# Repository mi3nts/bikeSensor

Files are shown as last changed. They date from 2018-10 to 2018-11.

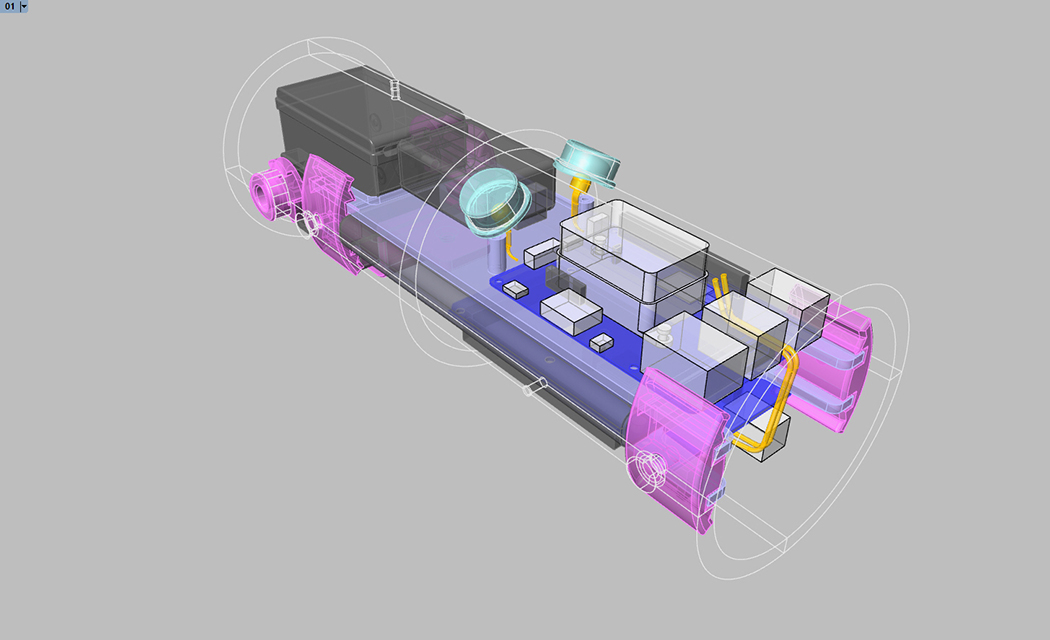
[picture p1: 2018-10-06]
resources/_bikeWaggle_03_FINAL.jpg

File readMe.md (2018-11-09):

# Bike Bottle Design Overview
## Introduction 
Portable devices which can detect airbourne particulates are finding its way into current consumer markets. Unlike there bulky, stationary counterparts the small scale nature of such sensors feeds into a more user friendly, hazzle free platform. The current document proposes such a portable device designed to be fit within a bike bottle housing. Particulate matter is linked with a number of negative health outcomes. Such links are to be addressed with the use of the propesed device.

### Design Specifications  

#### Absolute Necessities 
1. Main Housing:
 - The enclosed device should fit a bike bottle housing.

2. OPC Sensor: 
 - Must have the Alhpa Sense OPC-N3 <br/>
   **http://www.alphasense.com/WEB1213/wp-content/uploads/2018/02/OPC-N3.pdf** <br/>      

3. Automated Notifications 
 - Should sound an alarm when passing through dirty air. 

4. Secondary Sensors: 
- Must have Temprature, Humidity, Pressure and GPS sensors.   

5. Battery:
- Must contain a rechargable portable battery which will enable the device to stay on for atleast for 4 hours.
- Must have an indicator which shows the status of the battery Charge.
- Should be able to work 24*7 when connected to power(Charging pod).

6. Date Storage: 
- The device should be capable of storing at least 24 hours of Data.  
- The Storage output should be a csv 
- Should be accessible to the end user 

7. Weight 
- Must weigh less than 1 Kg.

8. Cost 
- The Whole sensor should cost less than 2000$.

##### Attractive Addons 

1. Secondary Sensors: 
- Inclusion of gas sensors such as NO2 (Nitrogen Dioxide), O3 (Ozone), CO (Carbon Monoxide), SO2 (Sulfer Dioxide), and H2S (Hydrogen Sulfide). 

2. Battery:
- A portable battery which will enable the device to stay on for atleast **24 hours** per charge.

3. Date Storage: 
- Automated Cloud link

4. Mobile App
- Inclusion of an andorid/ios app which will give out live statistics from the data collected.

5. Weight 
- Weigh less than 500g.

6. Cost 
- Getting the cost to be less than 1000$.

7. Wireless Connectivity 
- Inlcussion of a wireless modem and have the possibiilty of WiFi.

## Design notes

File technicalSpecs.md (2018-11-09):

# Bike Sensor
This document specifies the technical specifications for the Bike Waggle Sensor.

## 1.0 Sensor Brain : [Particle Photon](https://docs.particle.io/datasheets/photon-(wifi)/photon-datasheet/)
The main platform used: [Particle IO](https://www.particle.io/). For the sensor brain two options were considered.
- Particle [Photon](https://docs.particle.io/datasheets/photon-(wifi)/photon-datasheet/) : Works with Wi - Fi
- Particle [Electron](https://docs.particle.io/datasheets/electron-(cellular)/electron-datasheet/) : Works on Cellular Data 

It was finalized that **Particle Photon** was to be used due to cost constraints. 

### 1.1 Devices Connecting to the Sensor Brain(Particle Photon)
The sensor hub will be responsible in reading the follwing inputs.

| Part Name | Measurment | Interface  |
|---|---|---|
| GPS Module [NEO-6M](https://www.amazon.com/DIYmall-AeroQuad-Antenna-Arduino-Aircraft/dp/B01H5FNA4K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) | Long/Lat Speed and Altitude  |  RS232 TTL |
| SD Breakout Board [Adafruit-MicroSD](https://www.adafruit.com/product/254) | Read/Write SD | SPI mode |
| RTC Battery [PCF8523](https://www.adafruit.com/product/3295) | Real Time Clock | I2C |
| Gyroscope [MPU9250](https://www.amazon.com/HiLetgo%C2%AE-Gyroscope-Acceleration-Accelerator-Magnetometer/dp/B01I1J0Z7Y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) | 3 axis acceleration - 3 axis orientation - 3 axis magnetometor| I2C|
| Temprature and Humidity Sensor [HTU2ID](https://www.adafruit.com/product/1899) | Temperature - Relative Humidity | I2C |
|Atmospheric Pressure Sensor [BMP280](https://www.amazon.com/Adafruit-BMP280-Barometric-Pressure-Altitude/dp/B01DXCNV2A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) | Temperature -  Atmospheric Pressure | I2C |
|  Alphasense Device [OPC-N3](http://www.alphasense.com/WEB1213/wp-content/uploads/2018/02/OPC-N3.pdf)  | 24 Bin Counts of 0.38 to 40um Spherical Diemetor - PM1 - PM2.5 - PM10| SPI Mode|
| LCD Display [Smraza 2004](https://www.amazon.com/Smraza-Display-characters-Arduino-MEGA2560/dp/B01K1N4XM6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) | Display Output | I2C |

## 2.0 Power Needs

A few more devices are required for a mobile working device. 

- Battery Packs:
    - [Battery Pack 1](https://www.amazon.com/BESWILL-10000MAH-Waterproof-Flashlights-Carabiner/dp/B07BSYZXRT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)
    - [Battery Pack 2](https://www.amazon.com/Portable-RAVPower-26800mAh-Protective-Hermitshell/dp/B01KX3854Q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)
    - [Battery Pack 3](https://www.amazon.com/Soluser-13500mAh-Portable-External-Flashlight/dp/B0728NQ1VK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)
- [Power Tester](https://www.amazon.com/DROK-Multimeter-Voltmeter-Capacitance-Charging/dp/B00J3JSEG6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)

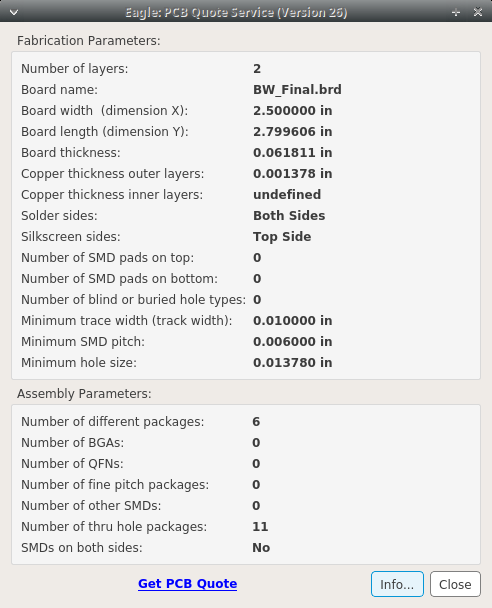
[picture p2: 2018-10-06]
pcbDesign/pcbDetails.png

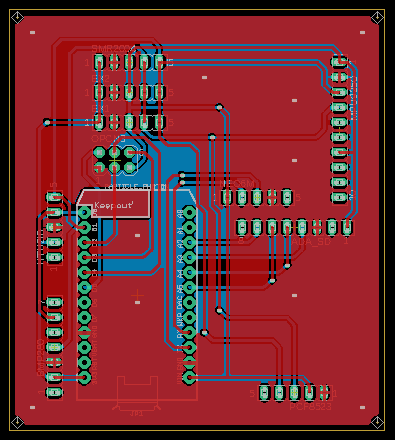
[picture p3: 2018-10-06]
pcbDesign/pcb.png

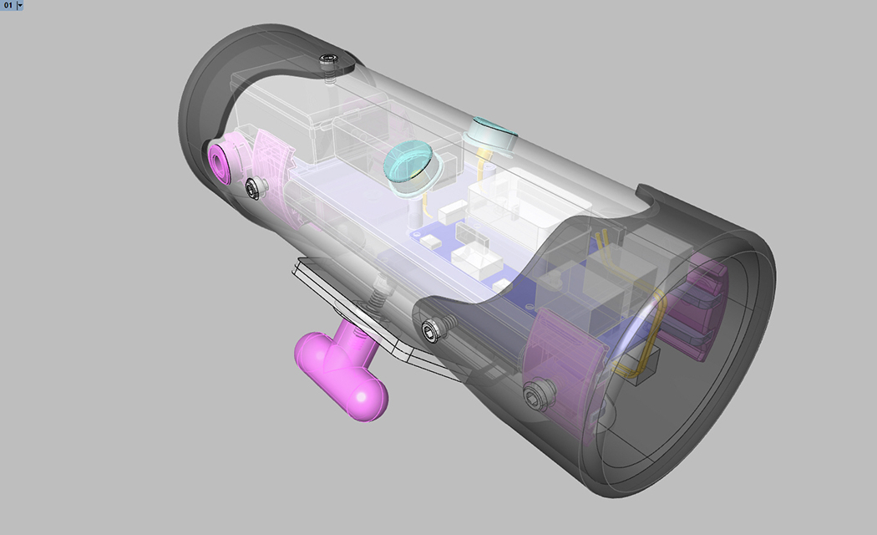
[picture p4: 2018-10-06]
resources/_bikeWaggle_02_FINAL.jpg

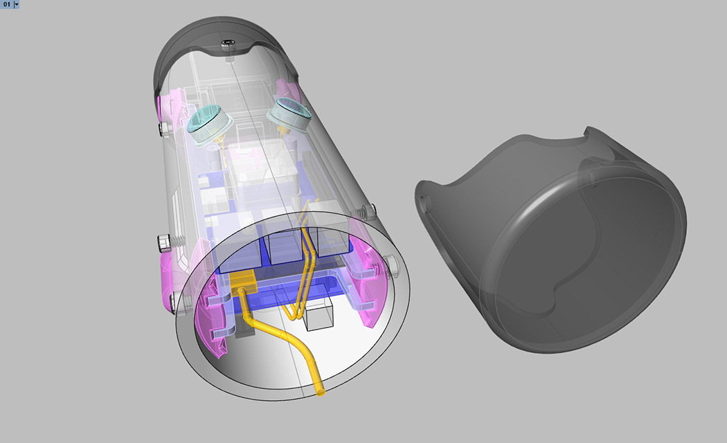
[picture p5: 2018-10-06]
resources/_bikeWaggle_07_FINAL.jpg

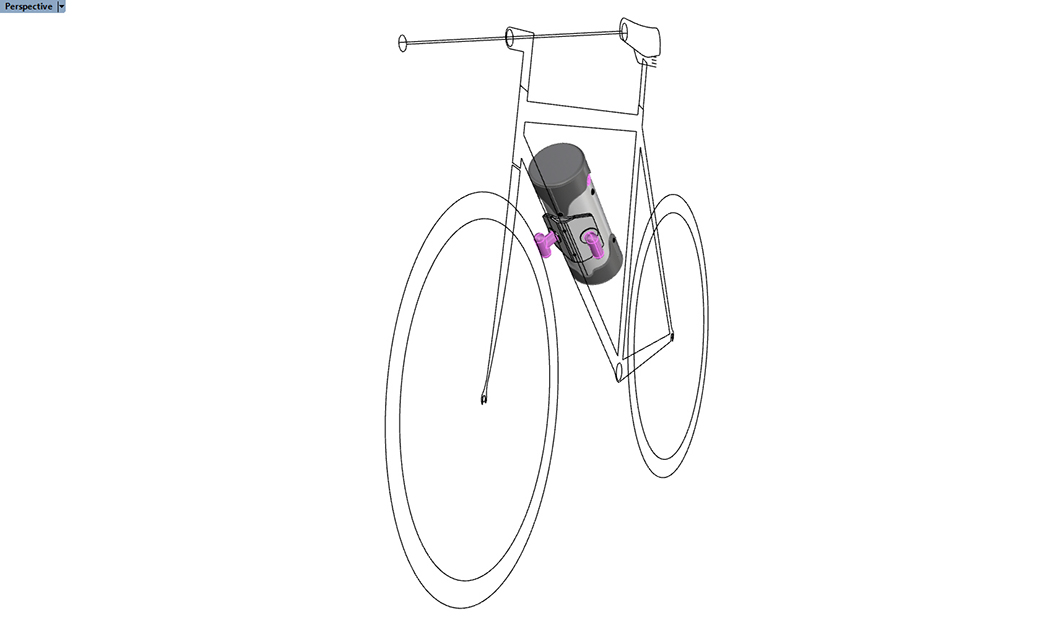
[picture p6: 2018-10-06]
resources/_bikeWaggle_10_FINAL.jpg

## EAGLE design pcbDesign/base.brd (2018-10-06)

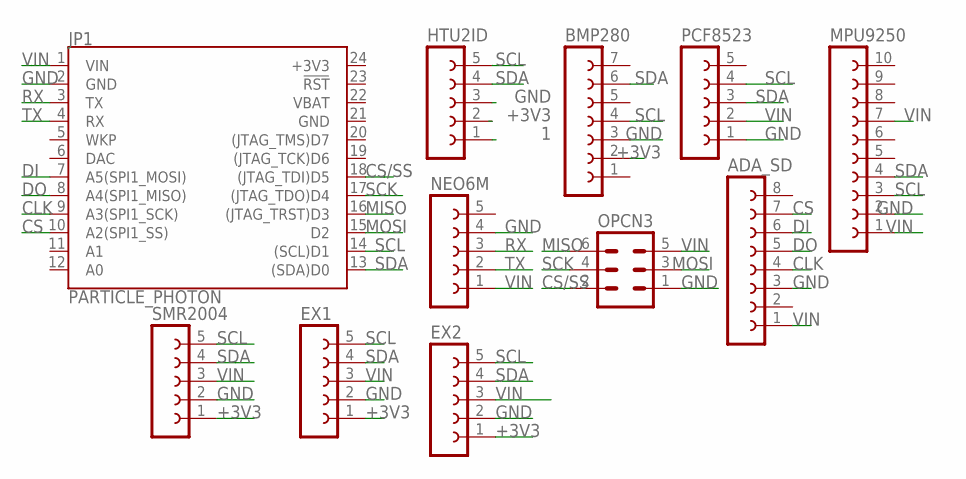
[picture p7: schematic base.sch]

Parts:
ADA_SD: FE08-1; FE08
BMP280: FE07-1; FE07
EX1, EX2: FE05-1
HTU2ID: FE05-1
JP1: PARTICLE_PHOTON
MPU9250: FE10-1; FE10
NEO6M: FE05-1
OPCN3: MA03-2
PCF8523: FE05-1
SMR2004: FE05-1

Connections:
1: HTU2ID.1
+3V3: BMP280.2, EX1.1, EX2.1, HTU2ID.2, JP1.24 (+3V3), SMR2004.1
CLK: ADA_SD.4, JP1.9 (A3(SPI1_SCK))
CS: ADA_SD.7, JP1.10 (A2(SPI1_SS))
CS/SS: JP1.18 ((JTAG_TDI)D5), OPCN3.2
DI: ADA_SD.6, JP1.7 (A5(SPI1_MOSI))
DO: ADA_SD.5, JP1.8 (A4(SPI1_MISO))
GND: ADA_SD.3, BMP280.3, EX1.2, EX2.2, HTU2ID.3, JP1.2 (GND), JP1.21 (GND), MPU9250.2, NEO6M.4, OPCN3.1, PCF8523.1, SMR2004.2
MISO: JP1.16 ((JTAG_TRST)D3), OPCN3.6
MOSI: JP1.15 (D2), OPCN3.3
RX: JP1.3 (TX), NEO6M.3
SCK: JP1.17 ((JTAG_TDO)D4), OPCN3.4
SCL: BMP280.4, EX1.5, EX2.5, HTU2ID.5, JP1.14 ((SCL)D1), MPU9250.3, PCF8523.4, SMR2004.5
SDA: BMP280.6, EX1.4, EX2.4, HTU2ID.4, JP1.13 ((SDA)D0), MPU9250.4, PCF8523.3, SMR2004.4
TX: JP1.4 (RX), NEO6M.2
VBAT: JP1.22 (VBAT)
VIN: ADA_SD.1, EX1.3, EX2.3, JP1.1 (VIN), MPU9250.1, MPU9250.7, NEO6M.1, OPCN3.5, PCF8523.2, SMR2004.3

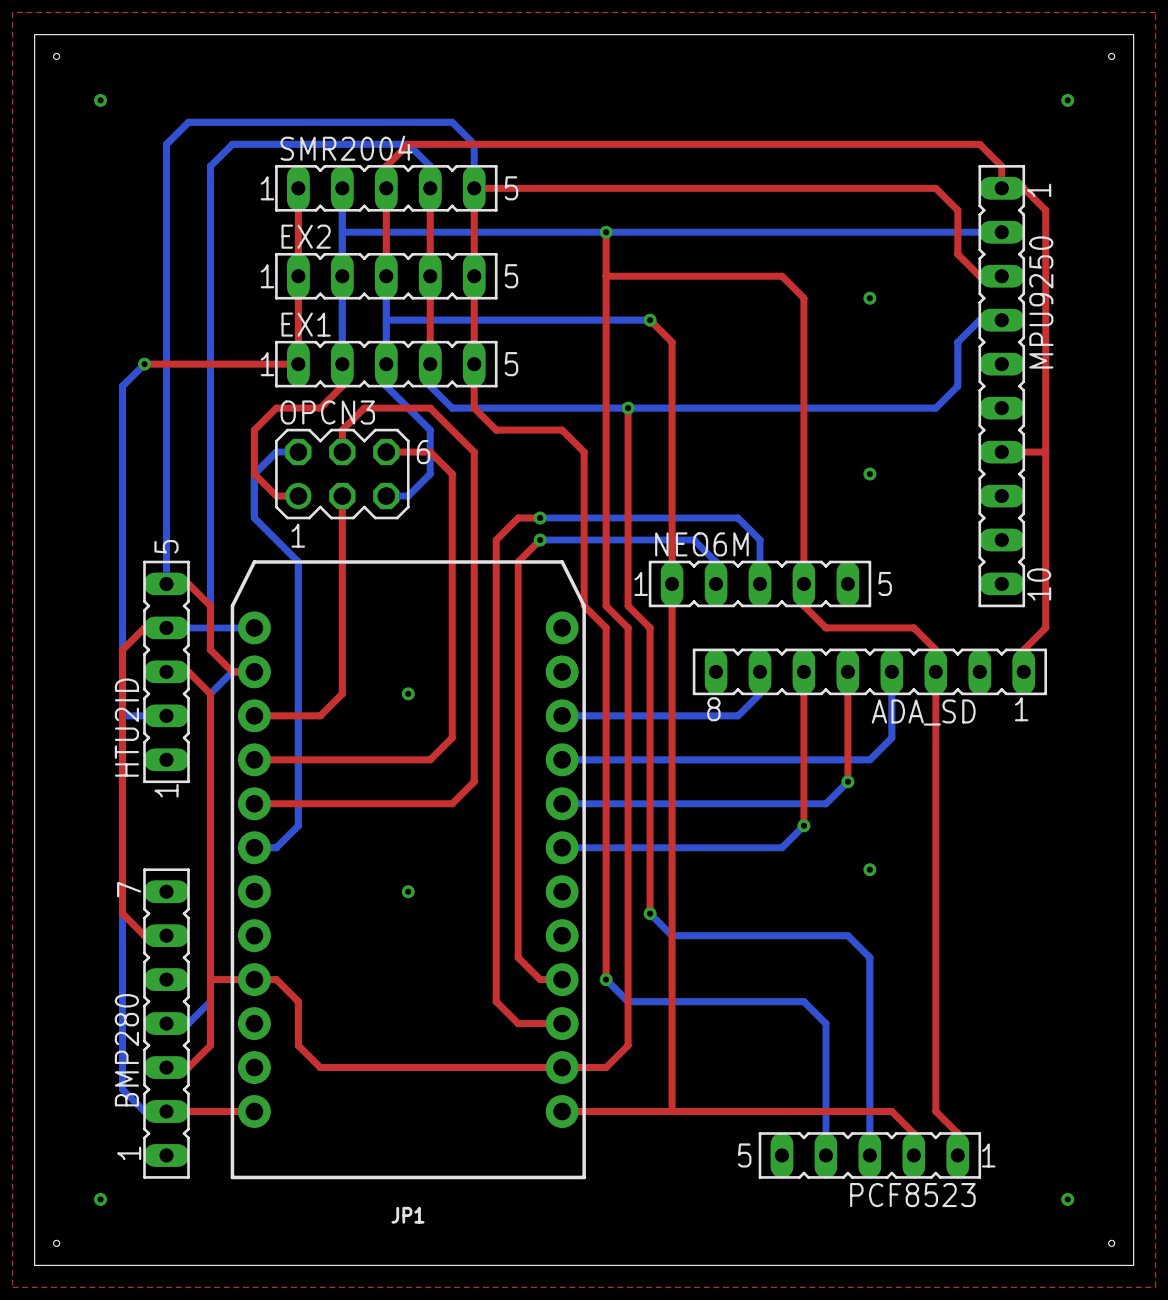
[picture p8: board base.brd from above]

Board: 2 copper layers, 63.5 x 71.1 mm, 11 parts (0 on the bottom side), 15 nets.

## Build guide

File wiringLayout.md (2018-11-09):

# The Wiring Layout for  the Bike Sensor
## Devices Used
The devices used for the Bike Waggle Project are listed below. 

| Device | Serial data link | Device Address |
|---|---|---|
| RTC(PCF8523)		 | I<sup>2</sup>C | 0x68 |
| LCD Module(Smraza 2004) | I<sup>2</sup>C | 0x3F |
| Gyroscope(MPU9250)  	 | I<sup>2</sup>C | 0x68/**0x69**  |
| GPS(NEO-6M) 	 | RS232 TTL 	| - |
| SD Module(Adafruit) | SPI 	| - |
| Temprature/Humidity(HTU2ID)  | I<sup>2</sup>C | 0x40 |
| Temprature/Pressure(BMP280)  | I<sup>2</sup>C | **0x76**/0x77  |
| Battery Pack | - | - |

The following are the wiring layouts used for all the devices in use:

### The Real Time Clock(PCF8523)
 
| Photon  |  PCF8523  | 
| ---  | --- |
| DO | SDA | 
| D1 | SCL | 
| VIN | VCC | 
| GND | GND | 

### The Temperature and Humidity Sensor(HTU2ID)

| Photon  |  HTU2ID | 
| ---  | --- |
| DO | SDA | 
| D1 | SCL | 
| 3V3 | VCC | 
| GND | GND | 

### The Temperature and Pressure Sensor(BMP280)

| Photon  |  BMP280 | 
| ---  | --- |
| DO | SDI | 
| D1 | SCK | 
| 3V3 | 3V0 | 
| GND | GND | 

### The Gyroscope (MPU9250)

| Photon  |  MPU9250  | 
| ---  | --- |
| DO | SDA | 
| D1 | SCL | 
| VIN | VCC | 
| GND | GND | 
| VIN | ADO | 

### GPS(NEO-6M)

| Photon  |  NEO-6M | 
| ---  | --- |
| RX | TX | 
| TX | RX | 
| VIN | VCC | 
| GND | GND | 

### SD Card(Adafruit MicroSD)

| Photon | SPI Name | SD Reader | 
| --- | --- | --- |
| A2 | SS | CS | 
| A3 | SCK | SCK | 
| A4 | MISO | DO | 
| A5 | MOSI | DI | 
| VIN | | 5V | 
| GND | | GND | 

### Alpha Sensor(OPCN3)

| Photon  |  OPCN3  | 
| ---  | --- |
| D2 | MOSI | 
| D3 | MISO | 
| D4 | SCK | 
| D5 | CS/SS | 
| VIN | VCC | 
| GND | GND | 

### LCD(-)
| Photon | LCD | 
| --- | --- |
| DO | SDA | 
| D1 | SCL | 
| VIN | VCC | 
| GND | GND |

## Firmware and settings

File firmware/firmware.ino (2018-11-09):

// This #include statement was automatically added by the Particle IDE.
#include <SdFat.h>
#include <Particle-GPS.h>
#include <Adafruit_BMP280.h>
#include "quaternionFilters.h"
#include "MPU9250.h"
#include <HTU21D.h>
#include "Sensorgram.h"
#include <RTClibrary.h>
#include "Jobs_BW.h"
#include "Devices_BW.h"
#include <LiquidCrystal_I2C_Spark.h>

//WI-FI CONNECTIVITY
SYSTEM_MODE(SEMI_AUTOMATIC)
SYSTEM_THREAD(ENABLED)


//SD Card
SdFat sd;
SdFile file;
File myFile;
String Bike_Waggle_ID =  "Lakithas_Photon";
const uint8_t chipSelect = A2;
int Sensorgram_Publish_Index;
int Sensorgram_Reading_Index;
bool SDFull = false;

// LCD - May not be used
LiquidCrystal_I2C *lcd;

//PCF8523
RTC_PCF8523 rtc;

//HTU2ID
HTU21D htu = HTU21D();
bool HTU2ID_Online = false;


//MPU9250
MPU9250 myIMU;
bool Device_Stable_MPU9250 = false;
bool MPU9250_Online = false;
bool Device_Stable = false;


//BMP280
bool BMP280_Online = false;
Adafruit_BMP280 bmp;

//NEO-6M
bool NEO6M_Online = false;
Gps _gps = Gps(&Serial1);
Timer _timer = Timer(1, onSerialData_BW);
bool Device_Stable_NEO6M = false;

//OPCN3
bool OPCN3_Online = false;
bool flagON = false;

int Period_When_Stable=250000;// Loop time when Stable in Seconds
int Min_Loop_Time=2000;
unsigned long Loop_Begin_Time;
// Define Master Switches for Each Sensor

bool OPCN3_Master = true;
bool MPU9250_Master = true;
bool NEO6M_Master = true;
bool BMP280_Master = true;
bool HTU2ID_Master = true;


uint8_t Time_Beg ;

bool Function_Registered=false;

// // Sensorgram(String SL, String SID,String SI,String SPID, String SST, String SF , String SD, String SSDT, String SSDS, String SSDP, String SHRF);
// // Data Organization for a Sensogram Object [Length (2B)] [Sensor_ID (2B)] [Sensor_Instance (1B)] [Parameter_ID (1B)] [ Sampling_Time (4B)] [ Data_Format (1B)] [data (xB)] + [SDTime]  [SD_Sensor] [SDParametor] [Humand_Readable_Data]

Sensorgram HTU2ID_Temperature("0004","00A3","00","00","00000000","1E","00","Date_Time","HTU2ID","Temperature","00") ;
Sensorgram HTU2ID_Humidity("0004","00A3","00","01","00000000","1E","00","Date_Time","HTU2ID","Humidity","00") ;

Sensorgram MPU9250_Accelaration_X("0004","00A6","00","00","00000000","1E","00","Date_Time","MPU9250","Acceleration_X","00") ;
Sensorgram MPU9250_Accelaration_Y("0004","00A6","00","01","00000000","1E","00","Date_Time","MPU9250","Acceleration_Y","00") ;
Sensorgram MPU9250_Accelaration_Z("0004","00A6","00","02","00000000","1E","00","Date_Time","MPU9250","Acceleration_Z","00") ;
Sensorgram MPU9250_Gyro_Rate_X("0004","00A6","00","03","00000000","1E","00","Date_Time","MPU9250","Gyro_Rate_X","00") ;
Sensorgram MPU9250_Gyro_Rate_Y("0004","00A6","00","04","00000000","1E","00","Date_Time","MPU9250","Gyro_Rate_Y","00") ;
Sensorgram MPU9250_Gyro_Rate_Z("0004","00A6","00","05","00000000","1E","00","Date_Time","MPU9250","Gyro_Rate_Z","00") ;
Sensorgram MPU9250_Magnetic_Feild_X("0004","00A6","00","06","00000000","1E","00","Date_Time","MPU9250","Mag_Feild_X","00") ;
Sensorgram MPU9250_Magnetic_Feild_Y("0004","00A6","00","07","00000000","1E","00","Date_Time","MPU9250","Mag_Feild_Y","00") ;
Sensorgram MPU9250_Magnetic_Feild_Z("0004","00A6","00","08","00000000","1E","00","Date_Time","MPU9250","Mag_Feild_Z","00") ;
Sensorgram MPU9250_Temperature("0004","00A6","00","09","00000000","1E","00","Date_Time","MPU9250","Temperature","00") ;

// For the BMP 280
Sensorgram BMP280_Temperature("0004","00A4","00","00","00000000","1E","00","Date_Time","BMP280","Temperature","00") ;
Sensorgram    BMP280_Pressure("0004","00A4","00","01","00000000","1E","00","Date_Time","BMP280","Pressure","00") ;

// For the NEO-6M

Sensorgram NEO6M_Longitude("0000","00A2","00","00","00000000","1E","00","Date_Time","NEO6M","Longitude","00") ;
Sensorgram NEO6M_Latitude("0000","00A2","00","01","00000000","1E","00","Date_Time","NEO6M","Latitude","00") ;
Sensorgram NEO6M_Altitude("0000","00A2","00","02","00000000","1E","00","Date_Time","NEO6M","Altitude","00") ;
Sensorgram NEO6M_Speed("0000","00A2","00","03","00000000","1E","00","Date_Time","NEO6M","Speed","00") ;
//

Sensorgram OPCN3_Bin_0("0000","00A1","00","00","00000000","0B","00","Date_Time","OPCN3","Bin0","00") ;
Sensorgram OPCN3_Bin_1("0000","00A1","00","01","00000000","0B","00","Date_Time","OPCN3","Bin1","00") ;
Sensorgram OPCN3_Bin_2("0000","00A1","00","02","00000000","0B","00","Date_Time","OPCN3","Bin2","00") ;
Sensorgram OPCN3_Bin_3("0000","00A1","00","03","00000000","0B","00","Date_Time","OPCN3","Bin3","00") ;
Sensorgram OPCN3_Bin_4("0000","00A1","00","04","00000000","0B","00","Date_Time","OPCN3","Bin4","00") ;
Sensorgram OPCN3_Bin_5("0000","00A1","00","05","00000000","0B","00","Date_Time","OPCN3","Bin5","00") ;
Sensorgram OPCN3_Bin_6("0000","00A1","00","06","00000000","0B","00","Date_Time","OPCN3","Bin6","00") ;
Sensorgram OPCN3_Bin_7("0000","00A1","00","07","00000000","0B","00","Date_Time","OPCN3","Bin7","00") ;
Sensorgram OPCN3_Bin_8("0000","00A1","00","08","00000000","0B","00","Date_Time","OPCN3","Bin8","00") ;
Sensorgram OPCN3_Bin_9("0000","00A1","00","09","00000000","0B","00","Date_Time","OPCN3","Bin9","00") ;
Sensorgram OPCN3_Bin_10("0000","00A1","00","0A","00000000","0B","00","Date_Time","OPCN3","Bin10","00") ;
Sensorgram OPCN3_Bin_11("0000","00A1","00","0B","00000000","0B","00","Date_Time","OPCN3","Bin11","00") ;
Sensorgram OPCN3_Bin_12("0000","00A1","00","0C","00000000","0B","00","Date_Time","OPCN3","Bin12","00") ;
Sensorgram OPCN3_Bin_13("0000","00A1","00","0D","00000000","0B","00","Date_Time","OPCN3","Bin13","00") ;
Sensorgram OPCN3_Bin_14("0000","00A1","00","0E","00000000","0B","00","Date_Time","OPCN3","Bin14","00") ;
Sensorgram OPCN3_Bin_15("0000","00A1","00","0F","00000000","0B","00","Date_Time","OPCN3","Bin15","00") ;
Sensorgram OPCN3_Bin_16("0000","00A1","00","10","00000000","0B","00","Date_Time","OPCN3","Bin16","00") ;
Sensorgram OPCN3_Bin_17("0000","00A1","00","11","00000000","0B","00","Date_Time","OPCN3","Bin17","00") ;
Sensorgram OPCN3_Bin_18("0000","00A1","00","12","00000000","0B","00","Date_Time","OPCN3","Bin18","00") ;
Sensorgram OPCN3_Bin_19("0000","00A1","00","13","00000000","0B","00","Date_Time","OPCN3","Bin19","00") ;
Sensorgram OPCN3_Bin_20("0000","00A1","00","14","00000000","0B","00","Date_Time","OPCN3","Bin20","00") ;
Sensorgram OPCN3_Bin_21("0000","00A1","00","15","00000000","0B","00","Date_Time","OPCN3","Bin21","00") ;
Sensorgram OPCN3_Bin_22("0000","00A1","00","16","00000000","0B","00","Date_Time","OPCN3","Bin22","00") ;
Sensorgram OPCN3_Bin_23("0000","00A1","00","17","00000000","0B","00","Date_Time","OPCN3","Bin23","00") ;
Sensorgram OPCN3_Bin_24("0000","00A1","00","18","00000000","0B","00","Date_Time","OPCN3","Bin24","00") ;

// PM Data
Sensorgram OPCN3_PM_1("0000","00A1","00","20","00000000","1E","00","Date_Time","OPCN3","PM1","00") ;
Sensorgram OPCN3_PM_2_5("0000","00A1","00","21","00000000","1E","00","Date_Time","OPCN3","PM2_5","00") ;
Sensorgram OPCN3_PM_10("0000","00A1","00","22","00000000","1E","00","Date_Time","OPCN3","PM10","00") ;

//
Sensorgram OPCN3_Sampling_Time("0000","00A1","00","30","00000000","0B","00","Date_Time","OPCN3","Sampling_Time","00") ;



void setup() {

Initialize_Serial_BW();
//delay(10000);
Serial.println("Device Started");
Initialize_SPI1();
Initialize_OPCN3_BW();
Initialize_LCD_BW();
Turn_WiFi_On_BW();


Initialize_HTU2ID_BW();
Initialize_MPU9250_BW();
Initialize_BMP280_BW();
Initialize_NEO6M_BW();
Initialize_SD_BW();
delay(1000);
Initialize_PCF8523_BW();
delay(1000);
Update_PCF8523_BW();

}

void loop() {

Loop_Begin_Time = millis();
Time_Beg  = millis();
if (HTU2ID_Master){
Serial.println("Reading HTU2ID");
Read_HTU2ID_BW();}
else{
HTU2ID_Online=false;
}
Serial.println("HTU21D Time:"+String(float(millis()-Time_Beg)/1000));

Time_Beg  = millis();
if (BMP280_Master){
Serial.println("Reading BMP280");
Read_BMP280_BW();}
else{
BMP280_Online=false;
}
Serial.println("BMP280 Time:"+String(float(millis()-Time_Beg)/1000));

Time_Beg  =millis();
if (MPU9250_Master){
Serial.println("Reading MPU9250");
Read_MPU9250_BW();}
else{
MPU9250_Online=false;
}
Serial.println("MPU9250 Time:"+String(float(millis()-Time_Beg)/1000));


Time_Beg  = millis();
if (NEO6M_Master){
Serial.println("Reading NEO6M");
Read_NEO6M_BW();}
else{
NEO6M_Online=false;
}
Serial.println("NEO6M Time:"+String(float(millis()-Time_Beg)/1000));

Time_Beg  = millis();
if (OPCN3_Master){
Serial.println("Reading OPCN3");
Read_OPCN3_BW();}
else{
OPCN3_Online=false;
}
Serial.println("OPCN3 Time:"+String(float(millis()-Time_Beg)/1000));
// print_debug();

Operational_LCD();
Serial.println("Function Registration Check");
Check_Function_Registration();

//Here the sensograms are put into a separate Sensorgram packets
Write_Sensorgram_Packets_To_SD_BW();
WiFi_Control_BW();

// Check_SD_Free_Space_BW();
Serial.println("Changes Made");
// Check_Function_Registration();
Halt_BW();
Serial.println("Final Loop Time:"+String(float(millis()-Loop_Begin_Time)/1000));
}// End of Loop

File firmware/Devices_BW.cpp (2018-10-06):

#include "Devices_BW.h"


// RTC Functionality  #################################################################################################################################

void Initialize_PCF8523_BW(){
  if (! rtc.begin()) {
    Serial.println("Couldn't find RTC");
    while (1);

    }
  if (! rtc.initialized()) {
    Serial.println("RTC is NOT running!");

   }
 }

void Update_PCF8523_BW(){

if (Particle.connected()){
  rtc.adjust(DateTime(Time.year(), Time.month(), Time.day(), Time.hour(), Time.minute(), Time.second()));
   }
}


String Get_Current_Time_SD_PCF8523_BW(DateTime RTC_Time){
return String::format("%04d:%02d:%02d:%02d:%02d:%02d",RTC_Time.year(),RTC_Time.month(),RTC_Time.day(),RTC_Time.hour(),RTC_Time.minute(),RTC_Time.second());
}


String Get_Current_Time_HEX_PCF8523_BW(DateTime RTC_Time){
return String(RTC_Time.unixtime(),HEX);
}

String Get_Current_Time_Bytes_PCF8523_BW(DateTime RTC_Time){
return String(RTC_Time.unixtime(),HEX);
}



String Get_Current_Time_LCD_PCF8523_BW(DateTime RTC_Time){
return String::format("%02d:%02d:%02d",RTC_Time.hour(),RTC_Time.minute(),RTC_Time.second());
}



// HTU 2ID Functionality  #################################################################################################################################

void Initialize_HTU2ID_BW(){
    	if(! htu.begin()){
	    Serial.println("HTU21D not found");

	}else{
	Serial.println("HTU21D OK");
	HTU2ID_Online =true;
	}
	//delay(1000);
}



void Read_HTU2ID_BW(){

  DateTime now = rtc.now();
  float  HTU2IDTemperature  = htu.readTemperature();
  float  HTU2IDHumidity     = htu.readHumidity();

        if (HTU2IDTemperature>-50&&HTU2IDTemperature<50)
        {
        HTU2ID_Online = true;
        HTU2ID_Temperature.Pack(Get_Current_Time_HEX(now),Float_32_to_Hex(&HTU2IDTemperature),Get_Current_Time_SD(now),String(HTU2IDTemperature));
        HTU2ID_Humidity.Pack(Get_Current_Time_HEX(now),Float_32_to_Hex(&HTU2IDHumidity),Get_Current_Time_SD(now),String(HTU2IDHumidity));
        Write_Data_To_SD_BW(HTU2ID_Temperature.Get_SD_Data());
        Write_Data_To_SD_BW(HTU2ID_Humidity.Get_SD_Data());
        }
}



// MPU9250 Functionality  #################################################################################################################################



void Initialize_MPU9250_BW(){

 // Read the WHO_AM_I register, this is a good test of communication
   byte c = myIMU.readByte(MPU9250_ADDRESS, WHO_AM_I_MPU9250);

  if (c == 0x73) // WHO_AM_I should always be 0x68
  {
    Serial.print("Check 3");
    Serial.println("MPU9250 is online...");

    // Start by performing self test and reporting values
    myIMU.MPU9250SelfTest(myIMU.SelfTest);

    Serial.print("x-axis self test: acceleration trim within : ");
    Serial.print(myIMU.SelfTest[0],1); Serial.println("% of factory value");
    Serial.print("y-axis self test: acceleration trim within : ");
    Serial.print(myIMU.SelfTest[1],1); Serial.println("% of factory value");
    Serial.print("z-axis self test: acceleration trim within : ");
    Serial.print(myIMU.SelfTest[2],1); Serial.println("% of factory value");
    Serial.print("x-axis self test: gyration trim within : ");
    Serial.print(myIMU.SelfTest[3],1); Serial.println("% of factory value");
    Serial.print("y-axis self test: gyration trim within : ");
    Serial.print(myIMU.SelfTest[4],1); Serial.println("% of factory value");
    Serial.print("z-axis self test: gyration trim within : ");
    Serial.print(myIMU.SelfTest[5],1); Serial.println("% of factory value");


    // Calibrate gyro and accelerometers, load biases in bias registers
    myIMU.calibrateMPU9250(myIMU.gyroBias, myIMU.accelBias);

    myIMU.initMPU9250();
    // Initialize device for active mode read of acclerometer, gyroscope, and
    // temperature
    Serial.println("MPU9250 initialized for active data mode....");

    // Read the WHO_AM_I register of the magnetometer, this is a good test of
    // communication
    byte d = myIMU.readByte(AK8963_ADDRESS, WHO_AM_I_AK8963);
    Serial.print("AK8963 "); Serial.print("I AM "); Serial.print(d, HEX);
    Serial.print(" I should be "); Serial.println(0x48, HEX);

    // Get magnetometer calibration from AK8963 ROM
    myIMU.initAK8963(myIMU.magCalibration);
    // Initialize device for active mode read of magnetometer

      //  Serial.println("Calibration values: ");
      Serial.print("X-Axis sensitivity adjustment value ");
      Serial.println(myIMU.magCalibration[0], 2);
      Serial.print("Y-Axis sensitivity adjustment value ");
      Serial.println(myIMU.magCalibration[1], 2);
      Serial.print("Z-Axis sensitivity adjustment value ");
      Serial.println(myIMU.magCalibration[2], 2);


  } // if (c == 0x73)
  else
  {
    Serial.print("Could not connect to MPU9250: 0x");
    Serial.println(c, HEX);
   // while(1) ; // Loop forever if communication doesn't happen
        }
}// End Initialize Gyro
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

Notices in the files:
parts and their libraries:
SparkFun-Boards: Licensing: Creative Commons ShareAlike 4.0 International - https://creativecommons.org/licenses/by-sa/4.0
